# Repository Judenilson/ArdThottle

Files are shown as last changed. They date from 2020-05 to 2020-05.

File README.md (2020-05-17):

# ArdThrottle

Manetes para uso com simulador de voo X-Plane
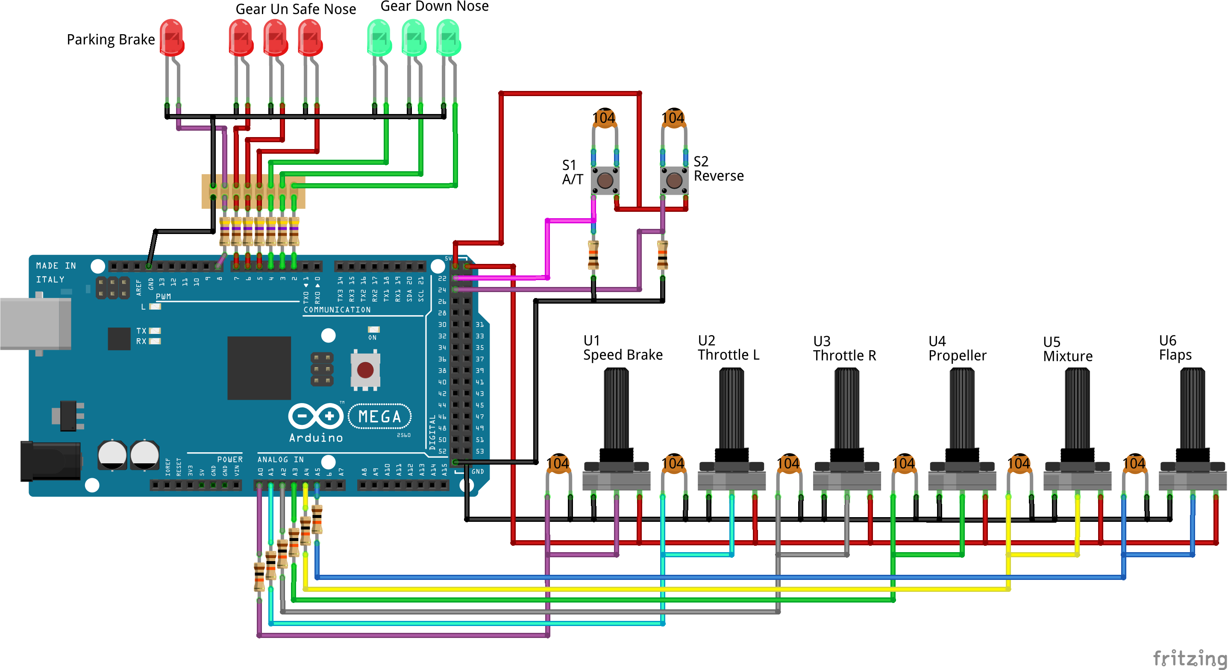
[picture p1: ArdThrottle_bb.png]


O Equipamento foi criado por mim, Judenilson Araujo, na intensão de disponibilizar um material de fácil entendimento para criação de plugins para o X-Plane usando a linguagem Python, aproveitando as funcionalidades do projeto [PYTHON INTERFACE PLUGIN](http://www.xpluginsdk.org/python_interface.htm) do Sandy Barbour.
Bem como, a utilização da placa [Arduino](https://www.arduino.cc/) MEGA ou UNO, com a finalidade de criar um hardware para controle do simulador. Integrada com o plugin desenvolvido em python, fazendo a conexão entre hardware e simulador.

Contudo, caso ainda não tenha, você precisará instalar a versão [2.7 do Python](http://www.python.org/download/), bem como, o plugin do Sandy.

Caso queira copiar o projeto, fique a vontade. Se fizer alguma alteração no código que vai melhorá-lo, por favor, compartilhe conosco.

### Instalação do Plugin:
Faça o download do repositório para o seu computador.
Suba a skecth do arduino usando o Visual Studio Code, após criar um novo projeto usando o plugin PlatformIO.
Ou renomeie o arquivo src/main.cpp para src/main.ino e suba diretamente usando a IDE do Arduino para sua placa.
Copie o arquivo PI_ArdThottle.py para a pasta /X-Plane11/Resources/plugins/PythonScripts/
Faça as ligações no seu hardware e divirta-se!

### Utilização do Plugin:
No menu do simulador, na lista de plugin vocẽ verá o ítem:
- ArdTHROTTLE
	- Conectar
	- Calibrar
	- About

Ao clicar, serão apresentadas as seguintes janelas:

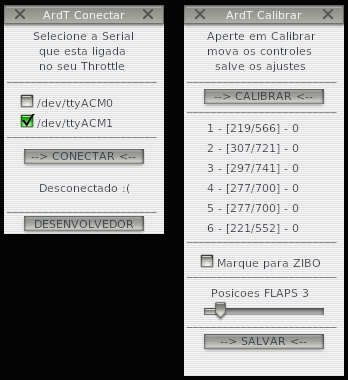
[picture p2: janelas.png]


#### ArdT Conectar:
Nessa janela você verá as portas de Comunicação Serial que estão disponíveis no seu PC.
Escolha a porta que seu Throttle está ligada e clique em CONECTAR.
Em seguida abra a janela calibrar.

#### ArdT Calibrar:
Aqui você poderá calibrar seu controle, bem como, escolher quantas posições de Flap sua aeronave possui, para garantir a precisão do ajuste.
Clique em calibrar e mova o controle para o início e fim do seu curso.
Clique em salvar.
Para ajustar a quantidade de posições de Flap, você não precisa clicar em calibrar, apenas mova o ajuste na barra e clique em salvar.

Todos os ajustes serão salvos num arquivo .JSON na pasta onde o plugin se encontra.
Portanto a cada vez que você reiniciar o simulador, não será preciso fazer uma nova configuração, porém será necessário clicar em CONECTAR, na janela ArdT Conectar, para conectar o simulador ao Hardware.

### Lista do material usado:

- Arduino MEGA ou UNO;
- 4 Leds Vermelhos
- 3 Leds Verdes
- 2 botões táctil (Mini Switch);
- 8 resistores 470R;
- 8 resistores 10k;
- 8 Capacitores cerâmico de 100nF;
- A carcaça será disponibilizada para impressão em 3D.

### Esquema desenhado no [Fritzing](https://www.fritzing.org)

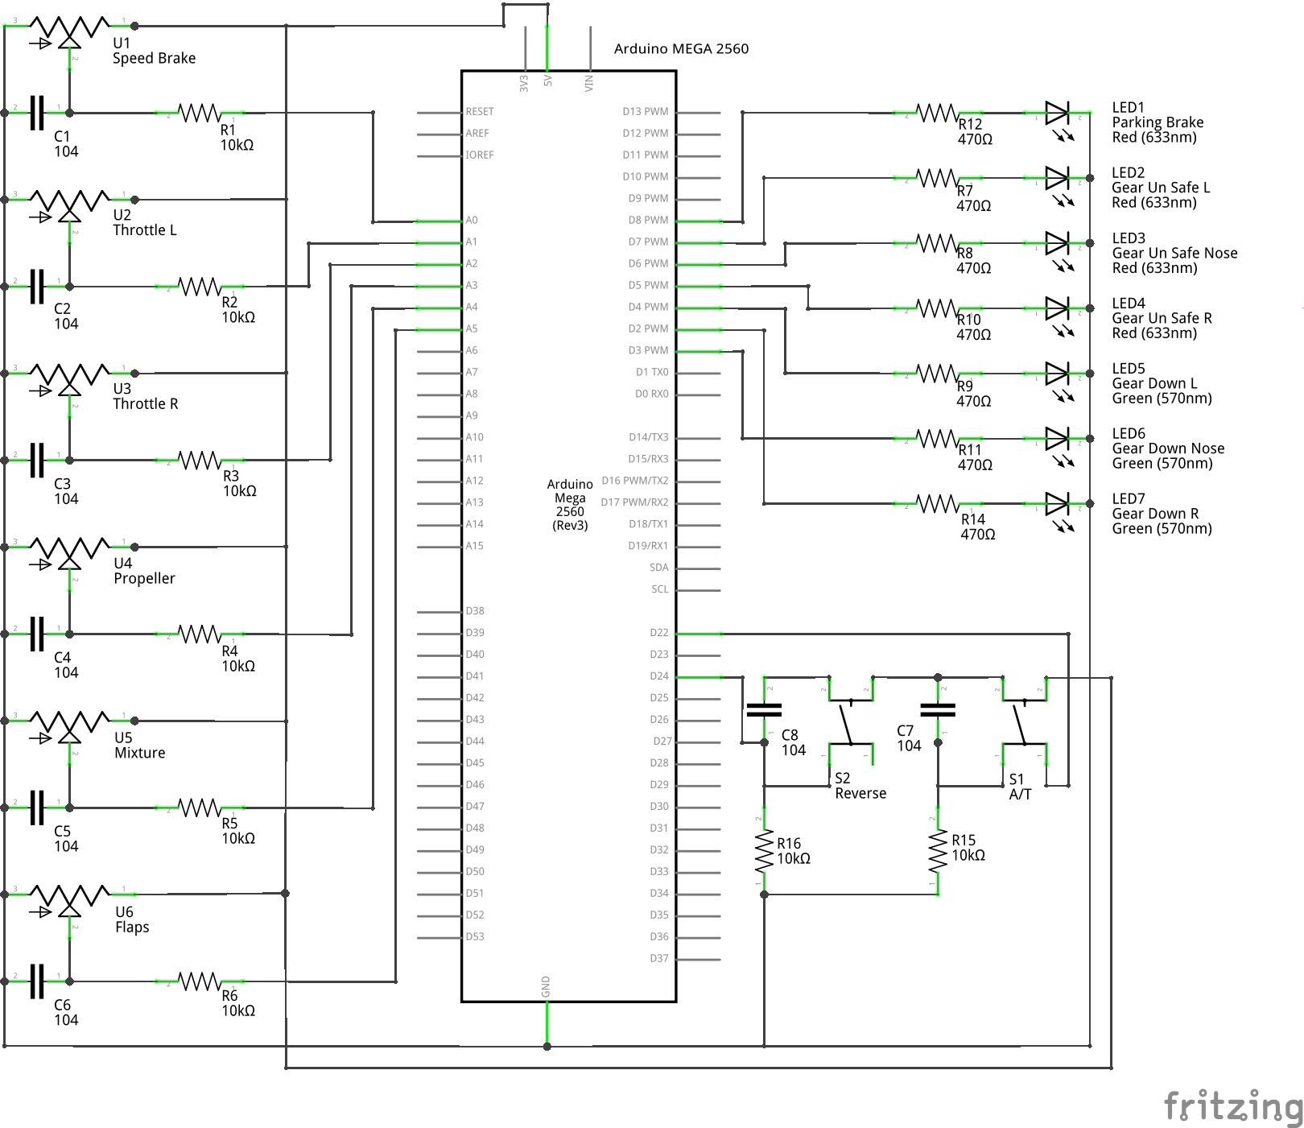
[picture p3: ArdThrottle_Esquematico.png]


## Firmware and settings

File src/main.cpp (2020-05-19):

#include <Arduino.h>

// Declarações dos Potenciômetros
#define potenciometroA A0
#define potenciometroB A1
#define potenciometroC A2
#define potenciometroD A3
#define potenciometroE A4
#define potenciometroF A5
// Declarações dos LEDS
#define	Right_Gear_Green 2
#define	Nose_Gear_Green 3
#define	Left_Gear_Green 4
#define	Right_Gear_Red 5
#define	Nose_Gear_Red 6
#define	Left_Gear_Red 7
#define	Parking_Brake_Ann 8
// Declarações dos Botões
#define AT 22
#define Reverse 24

// variáveis usadas para salvar o estado anterior dos potenciômetros
int potALastState = 0;
int potBLastState = 0;
int potCLastState = 0;
int potDLastState = 0;
int potELastState = 0;
int potFLastState = 0;
// variável para minimizar o ruído dos potenciômetros
int Correction = 5;
// variáveis para salvar as strings q serão enviadas via serial para o simulador
String dataPotenciometers = "P,0000,0000,0000,0000,0000,0000,"; // a vírgula do final serve para o split do python separar o valor do \n
String stateLEDS = "0000000";
// flag usada para controlar o envio de dados via serial, apenas quando existem mudanças nos dados.
bool flagSend = false;

void setup() {
  pinMode(potenciometroA, INPUT);
  pinMode(potenciometroB, INPUT);
  pinMode(potenciometroC, INPUT);
  pinMode(potenciometroD, INPUT);
  pinMode(potenciometroE, INPUT);
  pinMode(potenciometroF, INPUT);
  pinMode(Right_Gear_Green, OUTPUT);
  pinMode(Nose_Gear_Green, OUTPUT);
  pinMode(Left_Gear_Green, OUTPUT);
  pinMode(Right_Gear_Red, OUTPUT);
  pinMode(Nose_Gear_Red, OUTPUT);
  pinMode(Left_Gear_Red, OUTPUT);
  pinMode(Parking_Brake_Ann, OUTPUT);
  Serial.begin(115200);
  delay(1000);
}

void updateLEDS(){  // método para atualizar os LEDS
  if (stateLEDS[0] == '1'){
    digitalWrite(Nose_Gear_Red,1);
  }else{
    digitalWrite(Nose_Gear_Red,0);
  }
  if (stateLEDS[1] == '1'){
    digitalWrite(Nose_Gear_Green,1);
  }else{
    digitalWrite(Nose_Gear_Green,0);
  }
  if (stateLEDS[2] == '1'){
    digitalWrite(Right_Gear_Red,1);
  }else{
    digitalWrite(Right_Gear_Red,0);
  }
  if (stateLEDS[3] == '1'){
    digitalWrite(Right_Gear_Green,1);
  }else{
    digitalWrite(Right_Gear_Green,0);
  }
  if (stateLEDS[4] == '1'){
    digitalWrite(Left_Gear_Red,1);
  }else{
    digitalWrite(Left_Gear_Red,0);
  }
  if (stateLEDS[5] == '1'){
    digitalWrite(Left_Gear_Green,1);
  }else{
    digitalWrite(Left_Gear_Green,0);
  }
  if (stateLEDS[6] == '1'){
    digitalWrite(Parking_Brake_Ann,1);
  }else{
    digitalWrite(Parking_Brake_Ann,0);
  }
}

void serial(){  // método que verifica se existem dados para ler na porta serial
  if (Serial.available()) {
    char inChar = Serial.read();
    if (inChar == 'D'){
      for (int i=0; i<8; i++){
        char inSerial = Serial.read();
        if (inSerial == ','){
          updateLEDS();
          break;
        }
        stateLEDS[i] = inSerial;
      }
    }
  }
}

String INCZERO(int number){ // método para colocar zeros a esquerda
  String zeroFront = "";
  if (number < 1000){
    zeroFront += "0";
  }
  if (number < 100){
    zeroFront += "0";
  }
  if (number < 10){
    zeroFront += "0";
  }
  if (number <= 0){
    zeroFront += "0";
  }else{
    zeroFront += String(number);
  }
  return zeroFront;
}

void updatePot(int value, int position){  // método para atualizar os dados dos potenciômetros
  String valueString = "";
  valueString = INCZERO(value);
  int fimArray = (5*position)+1;
  int j = 0;
  for (int i=fimArray-4; i<fimArray; i++){
    dataPotenciometers[i] = valueString[j];
    j++;
  }  
  flagSend = true;  // ativar a flag para poder enviar os dados via serial
}

void loop() {
  // lendo os dados dos potenciômetros constantemente
  int potA = analogRead(potenciometroA);
  int potB = analogRead(potenciometroB);
  int potC = analogRead(potenciometroC);
  int potD = analogRead(potenciometroD);
  int potE = analogRead(potenciometroE);
  int potF = analogRead(potenciometroF);

  // se os dados dos potenciômetros + a correção mudarem, fazer a atualização da lista com os dados para transmitir
  if ((potA > (potALastState+Correction)) || (potA < (potALastState-Correction))){updatePot(potA, 1); potALastState = potA;}
  if ((potB > (potBLastState+Correction)) || (potB < (potBLastState-Correction))){updatePot(potB, 2); potBLastState = potB;}
  if ((potC > (potCLastState+Correction)) || (potC < (potCLastState-Correction))){updatePot(potC, 3); potCLastState = potC;}
  if ((potD > (potDLastState+Correction)) || (potD < (potDLastState-Correction))){updatePot(potD, 4); potDLastState = potD;}
  if ((potE > (potELastState+Correction)) || (potE < (potELastState-Correction))){updatePot(potE, 5); potELastState = potE;}
  if ((potF > (potFLastState+Correction)) || (potF < (potFLastState-Correction))){updatePot(potF, 6); potFLastState = potF;}
  
  // flag utilizada para enviar os dados via serial, apenas quando tem alteração
  if (flagSend){
    Serial.println(dataPotenciometers);
    flagSend = false; // fechando a flag para não ficar enviando dados sempre q o loop repete, e sem mudança nos dados
  }

  // chamando o método que analisa a entrada serial, a fim de receber dados do simulador
  serial();
}

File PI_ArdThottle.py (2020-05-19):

# Tem q instalar a biblioteca pyserial https://pypi.org/project/pyserial/
# in linux: sudo apt-get install python-pyserial
import serial
import sys
import glob
import serial.tools.list_ports
import json
# X-plane includes
from XPLMDefs import *
from XPLMProcessing import *
from XPLMDataAccess import *
from XPLMUtilities import *
from XPLMPlanes import *
from XPLMNavigation import *
from SandyBarbourUtilities import *
from PythonScriptMessaging import *
from XPLMPlugin import *
from XPLMMenus import *
from XPWidgetDefs import *
from XPWidgets import *
from XPStandardWidgets import *

class PythonInterface:
	def XPluginStart(self):
		self.Name = "ArdTHROTTLE"
		self.Sig =  "JUD.Python.ArdTHROTTLE"
		self.Desc = "Conecta o THROTTLE Arduino ao Simulador"
		self.MsgA = "Ard THROTTLE"
		self.MsgB = ""
		
		self.LEDS = "LD0000000,"
		self.LEDSLastState = "LD0000001,"		
		self.data = [0,0,0,0,0,0]
		self.Potenciometros = {"A":0.0,"B":0.0,"C":0.0,"D":0.0,"E":0.0,"F":0.0}
		self.throttleA = [0.0]
		self.throttleB = [0.0]
		
		self.flapsPositions = []
		self.flapsMedia = []
				
		self.portas = []
		self.ardSerial = serial.Serial()
		self.connected = False		
		ports = serial.tools.list_ports.comports()
		for port, desc, hwid in sorted(ports):
			self.portas.append(port)
		self.qtdPortas = len(self.portas)		
		self.portasWidgets=[]

		self.configs = {'portaCOM':'_',
										'aircraft':'',
										'qtdFlaps':3,
										'stepSpeedBMin':200,
										'stepSpeedBMax':750,
										'stepThrottleLMin':200,
										'stepThrottleLMax':750,
										'stepThrottleRMin':200,
										'stepThrottleRMax':750,
										'stepPropellerMin':200,
										'stepPropellerMax':750,
										'stepMixtureMin':200,
										'stepMixtureMax':750,
										'stepFlapMin':200,
										'stepFlapMax':750,										
										'stepPropellerAdjustMin':105.0,
										'stepPropellerAdjustMax':230.0,
										}

		self.openConfig()
		self.configflaps()
		self.calibrar = False
		self.ziboDRef = False
		
		self.aircraftType = ['zibo']
		self.aircraftMsg = ['Marque para ZIBO']

		self.DataRefSpeedBrake = XPLMFindDataRef("sim/cockpit2/controls/speedbrake_ratio")
		self.DataRefThrottle = XPLMFindDataRef("sim/cockpit2/engine/actuators/throttle_ratio")
		self.DataRefMixtureAll = XPLMFindDataRef("sim/cockpit2/engine/actuators/mixture_ratio_all")
		self.DataRefPropellerAll = XPLMFindDataRef("sim/cockpit2/engine/actuators/prop_rotation_speed_rad_sec_all") #105.0 - 230.0
		self.DataRefFlap = XPLMFindDataRef("sim/cockpit2/controls/flap_ratio")

		self.DataRefGear1def = XPLMFindDataRef("sim/flightmodel/movingparts/gear1def")
		self.DataRefGear2def = XPLMFindDataRef("sim/flightmodel/movingparts/gear2def")
		self.DataRefGear3def = XPLMFindDataRef("sim/flightmodel/movingparts/gear3def")
		
		self.DataRefParkingBrake = XPLMFindDataRef("sim/cockpit2/controls/parking_brake_ratio")

		self.Floop = self.FloopCallback
		XPLMRegisterFlightLoopCallback(self, self.Floop, 1.0, 0)

		# Menu / About
		self.Mmenu = self.mainMenuCB
		self.configWindow = False
		self.calibrarWindow = False
		self.aboutWindow = False
		self.mPluginItem = XPLMAppendMenuItem(XPLMFindPluginsMenu(), 'ArdTHROTTLE', 0, 1)
		self.mMain       = XPLMCreateMenu(self, 'ArdTHROTTLE', XPLMFindPluginsMenu(), self.mPluginItem, self.Mmenu, 0)

		# Menu Items
		XPLMAppendMenuItem(self.mMain, 'Conectar', 1, 1)
		XPLMAppendMenuItem(self.mMain, 'Calibrar', 2, 1)
		XPLMAppendMenuItem(self.mMain, 'Sobre', 3, 1)

		return self.Name, self.Sig, self.Desc

	def ZIBODataREF(self):
		# Data Refs do ZIBO
		self.ZIBODataRefFlap = XPLMFindDataRef("laminar/B738/flt_ctrls/flap_lever")
		self.ZIBODataRefSpeedBrake = XPLMFindDataRef("laminar/B738/flt_ctrls/speedbrake_lever")
		self.ZIBODataRefSpeedBrakeStop = XPLMFindDataRef("laminar/B738/flt_ctrls/speedbrake_lever_stop")
		self.ziboDRef = True
		return 1

	def mainMenuCB(self, menuRef, menuItem):
		if menuItem == 1:
			if not self.configWindow:
				self.createConfigWindow()
				self.configWindow = True
			elif (not XPIsWidgetVisible(self.configWindowWidget)):
				XPShowWidget(self.configWindowWidget)

		elif menuItem == 2:
			if not self.calibrarWindow:
				self.createCalibrarWindow()
			elif not XPIsWidgetVisible(self.calibrarWindowWidget):
				XPShowWidget(self.calibrarWindowWidget)

		elif menuItem == 3:
			if not self.aboutWindow:
				self.createAboutWindow()
			elif not XPIsWidgetVisible(self.aboutWindowWidget):
				XPShowWidget(self.aboutWindowWidget)

	def createConfigWindow(self):
		# (left, top, bottom, right) lefto, esquerda, base, direita - A origem e no canto inferior esquerdo!
		left = 240
		top = 540
		right = left + 160
		bottom = top - 188 - (20 * (self.qtdPortas))
		leftRst = left + 20 #com margem
		topRst = top
		rightRst = right - 20 #com margem
		bottomRst = bottom
		Titulo = "ArdT Conectar"
		separador = '_________________________'

		# criando a janela principal
		self.configWindowWidget = XPCreateWidget(left, top, right, bottom, 1, Titulo, 1, 0, xpWidgetClass_MainWindow)
		window = self.configWindowWidget
		XPSetWidgetProperty(window, xpProperty_MainWindowHasCloseBoxes, 1) # botao de fechar a janela, simples assim hehe

		# aviso
		left += 20		
		right -= 20
		top -= 20
		bottom = top - 15
		XPCreateWidget(left-2, top, right, bottom, 1, '  Selecione a Serial', 0, window, xpWidgetClass_Caption)
		top -= 15
		bottom = top - 15
		XPCreateWidget(left, top, right, bottom, 1,   '   que esta ligada', 0, window, xpWidgetClass_Caption)
		top -= 15
		bottom = top - 15
		XPCreateWidget(left, top, right, bottom, 1,   '   no seu Throttle', 0, window, xpWidgetClass_Caption)

		top -= 15
		bottom = top - 5
		self.separatorA = XPCreateWidget(left-20, top, right+20, bottom, 1, separador, 0, window, xpWidgetClass_Caption)
		
		# radios botoes das portas seriais
		self.portasWidgets = []
		for i in range(self.qtdPortas):
			top -= 20
			bottom = top - 20
			right = left + 5
			self.portasWidgets.append(XPCreateWidget(left, top, right, bottom, 1, '', 0, window, xpWidgetClass_Button))
			left = right + 5
			right = rightRst
			XPCreateWidget(left, top, right, bottom, 1, self.portas[i], 0, window, xpWidgetClass_Caption)
			left = leftRst

		for i in range(self.qtdPortas):
			XPSetWidgetProperty(self.portasWidgets[i], xpProperty_ButtonType, xpRadioButton)
			XPSetWidgetProperty(self.portasWidgets[i], xpProperty_ButtonBehavior, xpButtonBehaviorCheckBox)
			XPSetWidgetProperty(self.portasWidgets[i], xpProperty_ButtonState, int(self.configs['portaCOM'] == self.portas[i]))

		top -= 15
		bottom = top - 5
		self.separatorB = XPCreateWidget(left-20, top, right+20, bottom, 1, separador, 0, window, xpWidgetClass_Caption)

		top -= 20
		bottom = top - 20
		self.connectArduino = XPCreateWidget(left, top, right, bottom, 1, "--> CONECTAR <--", 0, window, xpWidgetClass_Button)
		XPSetWidgetProperty(self.connectArduino, xpProperty_ButtonType, xpPushButton)
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

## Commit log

2020-05-17 Primeiro Commit
    [ArdThrottle.fzz]
2020-05-19 Adicionado Datarefs para B738 ZIBO MOD
2020-05-22 correção no nome throttle
2020-05-29 Colocado try para pular algum erro serial
2020-05-31 imagem da janela com opção para ZIBO
2020-07-31 Diminuição do tempo de atualização do método principal
